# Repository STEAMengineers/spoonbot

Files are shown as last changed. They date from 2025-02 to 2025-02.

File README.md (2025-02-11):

# spoonbot
Spoonbot is a social energy indicator robot pcb based on a CH32v003J4M6 microcontroller, using a thumbwheel potentiometer to light some or all of the 5 leds.  It was designed for a smd soldering workshop we ran with MCQN at DoES Livepool.

This repo contains the code for the microcontroller and a kicad version of the pcb design. Because we used JLC colour silkscreen for our badges the hardware folder is an export from EasyEDA. It is highly recommended that you run DRC on the pcb before exporting for production.

Licence generated by OSHWA certification mark generator

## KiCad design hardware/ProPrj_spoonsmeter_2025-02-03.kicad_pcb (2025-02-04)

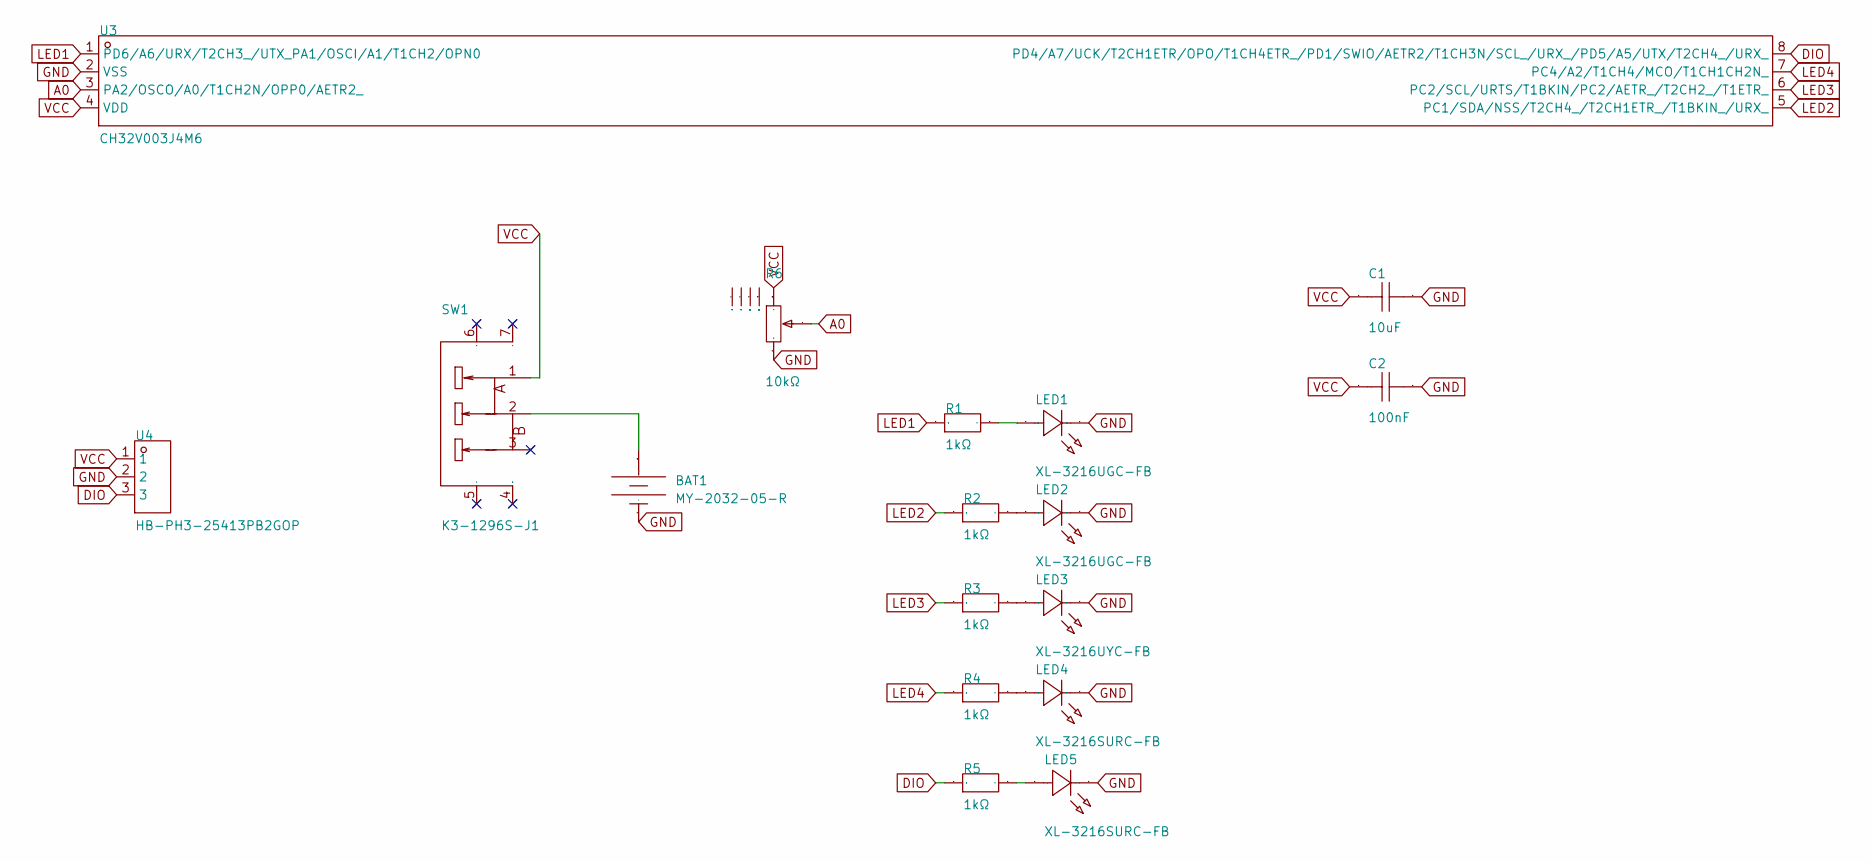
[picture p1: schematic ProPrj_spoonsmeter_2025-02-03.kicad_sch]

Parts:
BAT1: MY-2032-05-R; BAT-SMD_MY-2032-05-R; Manufacturer Part MY-2032-05-R; LCSC Part Name 电池扣 适用电池:CR2032
C1: 10uF; C0805; Manufacturer Part C0805X106K010T; LCSC Part Name 10uF ±10% 10V
C2: 100nF; C0805; Manufacturer Part C0805X104K251T; LCSC Part Name 100nF ±10% 250V
LED1, LED2: XL-3216UGC-FB; LED1206-RD_RED_LTST-C230CKT; Manufacturer Part XL-3216UGC-FB; LCSC Part Name XL-3216UGC-FB
LED3: XL-3216UYC-FB; LED1206-RD_RED_LTST-C230CKT; Manufacturer Part XL-3216UYC-FB; LCSC Part Name XL-3216UYC-FB
LED4, LED5: XL-3216SURC-FB; LED1206-RD_RED_LTST-C230CKT; Manufacturer Part XL-3216SURC-FB; LCSC Part Name XL-3216SURC-FB
R1, R2, R3, R4, R5: 1kΩ; R0805; Manufacturer Part SCR0805J1K; LCSC Part Name 厚膜电阻 1kΩ ±5% 125mW
R6: 10kΩ; RES-SMD_RK10J11R0A0H; Manufacturer Part RK10J11R0A0H; LCSC Part Name 10kΩ ±30%
SW1: K3-1296S-J1; SW-SMD_K3-1296S-J1; Manufacturer Part K3-1296S-J1; LCSC Part Name 柄长2.3mm卧贴双档 滑动开关
U3: CH32V003J4M6; SOP-8_L4.9-W3.8-P1.27-LS6.0-BL; Manufacturer Part CH32V003J4M6; LCSC Part Name CH32V003J4M6
U4: HB-PH3-25413PB2GOP; HDR-TH_3P-P2.54-V-M; Manufacturer Part HB-PH3-25413PB2GOP; LCSC Part Name 间距:2.54mm 1x3P 直插 方针

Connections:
$1N1644: BAT1.1 (+), SW1.2
$1N2487: LED3.2 (A), R3.2
$1N2528: LED2.2 (A), R2.2
$1N2533: LED4.2 (A), R4.2
$1N2535: LED1.2 (A), R1.2
$1N2553: LED5.2 (A), R5.2
A0: R6.2, U3.3 (PA2/OSCO/A0/T1CH2N/OPP0/AETR2_)
DIO: R5.1, U3.8 (PD4/A7/UCK/T2CH1ETR/OPO/T1CH4ETR_/PD1/S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), U4.3
GND: BAT1.2 (-), C1.2, C2.2, LED1.1 (K), LED2.1 (K), LED3.1 (K), LED4.1 (K), LED5.1 (K), R6.3, U3.2 (VSS), U4.2
LED1: R1.1, U3.1 (PD6/A6/URX/T2CH3_/UTX_PA1/OSCI/A1/T1CH2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)
LED2: R2.1, U3.5 (PC1/SDA/NSS/T2CH4_/T2CH1ETR_/T1BKIN_/UR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)
LED3: R3.1, U3.6 (PC2/SCL/URTS/T1BKIN/PC2/AETR_/T2CH2_/T1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)
LED4: R4.1, U3.7 (PC4/A2/T1CH4/MCO/T1CH1CH2N_)
VCC: C1.1, C2.1, R6.1, SW1.1, U3.4 (VDD), U4.1

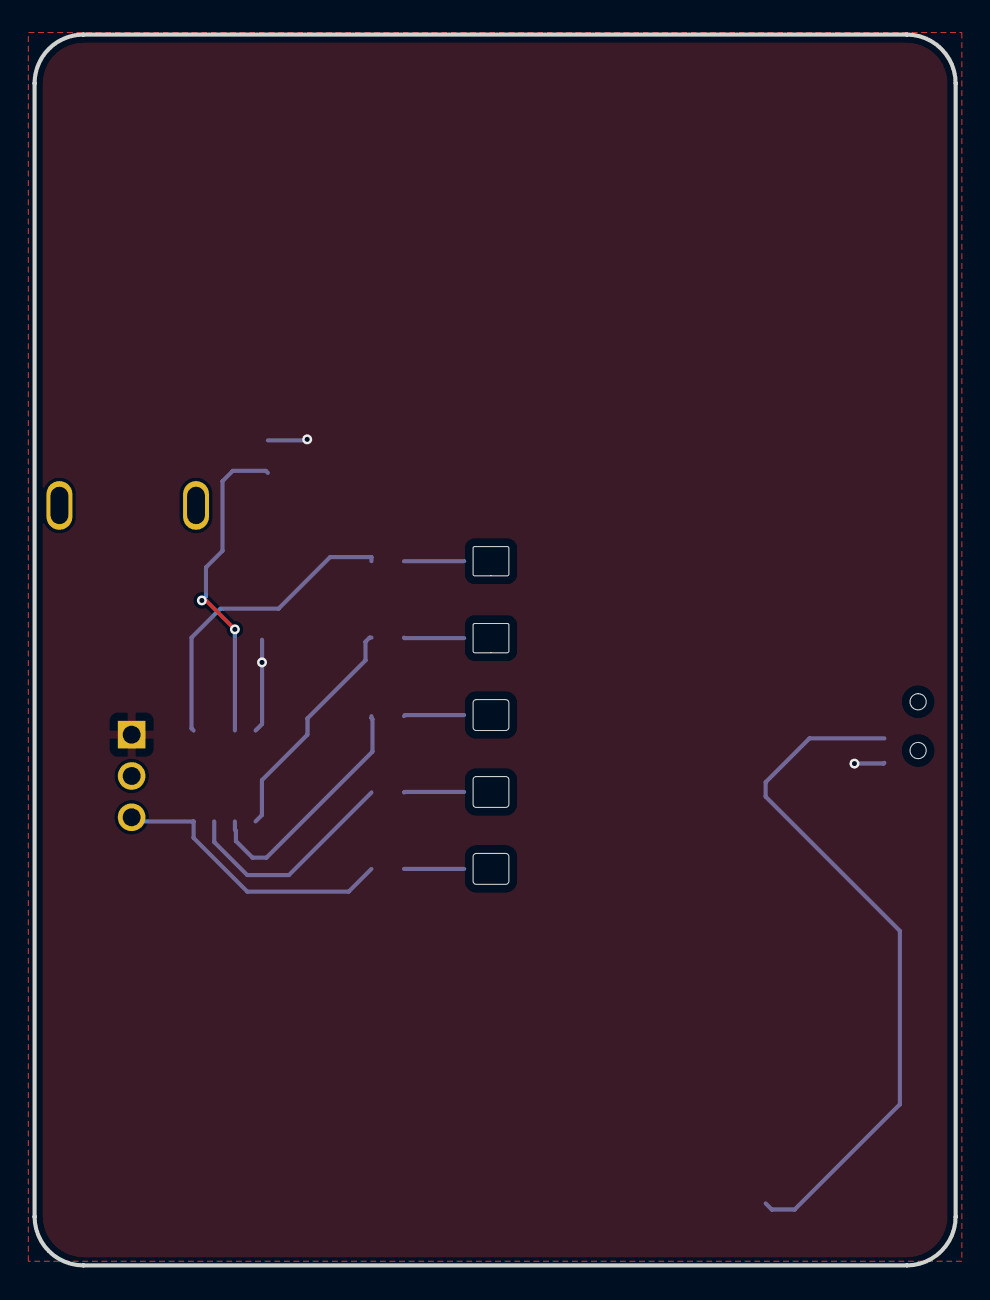
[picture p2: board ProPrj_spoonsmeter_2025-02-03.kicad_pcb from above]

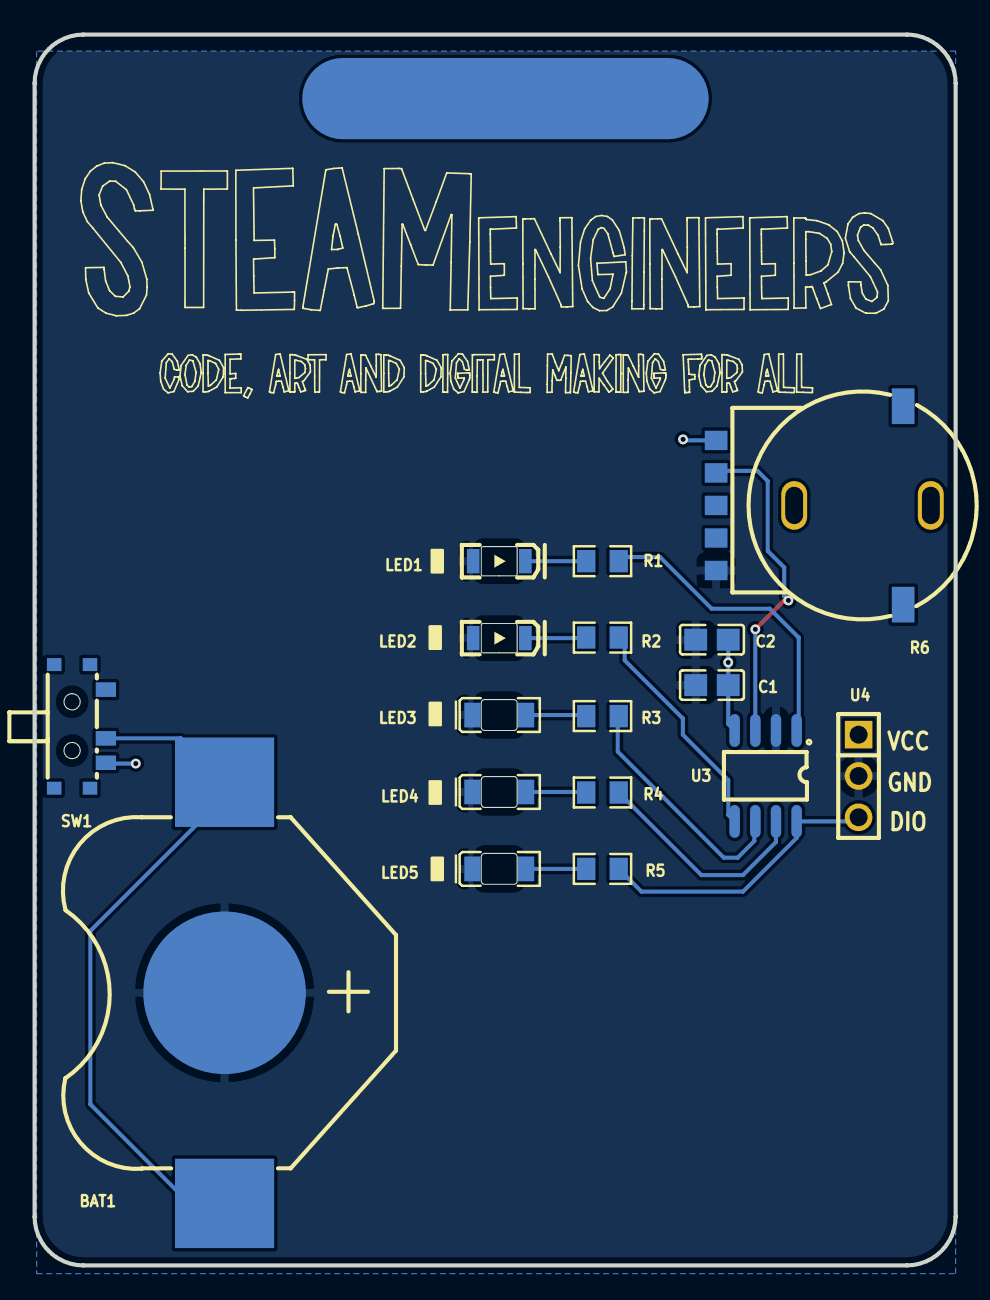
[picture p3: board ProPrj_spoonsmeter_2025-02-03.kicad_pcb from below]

Board: 2 copper layers, 56.6 x 75.7 mm, 17 parts (17 on the bottom side), 14 nets.

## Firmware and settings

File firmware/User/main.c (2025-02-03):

/********************************** (C) COPYRIGHT *******************************
 * File Name          : main.c
 * Author             : WCH
 * Version            : V1.0.0
 * Date               : 2023/12/25
 * Description        : Main program body.
 *********************************************************************************
 * Copyright (c) 2021 Nanjing Qinheng Microelectronics Co., Ltd.
 * Attention: This software (modified or not) and binary are used for 
 * microcontroller manufactured by Nanjing Qinheng Microelectronics.
 *******************************************************************************/

/*
 *@Note
 *Multiprocessor communication mode routine:
 *Master:USART1_Tx(PD5)\USART1_Rx(PD6).
 *This routine demonstrates that USART1 receives the data sent by CH341 and inverts
 *it and sends it (baud rate 115200).
 *
 *Hardware connection:PD5 -- Rx
 *                     PD6 -- Tx
 *
 */

#include "debug.h"


/* Global define */


/* Global Variable */
vu8 val;

/*********************************************************************
 * @fn      init_gpio
 *
 * @brief   Initializes PC1,2 & 4 and PA1.
 *
 * @return  none
 */
void init_gpio(void)
{
    ADC_InitTypeDef ADC_InitStructure = {0};
    GPIO_InitTypeDef  GPIO_InitStructure = {0};

    RCC_APB2PeriphClockCmd(RCC_APB2Periph_GPIOC | RCC_APB2Periph_GPIOA | RCC_APB2Periph_GPIOD, ENABLE);

    /* Port C1=led2 2=led3 4=led4 */
    GPIO_InitStructure.GPIO_Pin = GPIO_Pin_1 | GPIO_Pin_2 | GPIO_Pin_4;
    GPIO_InitStructure.GPIO_Speed = GPIO_Speed_30MHz;
    GPIO_InitStructure.GPIO_Mode = GPIO_Mode_Out_PP;
    GPIO_Init(GPIOC, &GPIO_InitStructure);

    /* Port D6=led1 D4=led5*/
    GPIO_InitStructure.GPIO_Pin = GPIO_Pin_6 | GPIO_Pin_4;
    GPIO_InitStructure.GPIO_Speed = GPIO_Speed_30MHz;
    GPIO_InitStructure.GPIO_Mode = GPIO_Mode_Out_PP;
    GPIO_Init(GPIOD, &GPIO_InitStructure);

    /* Port A0*/

     RCC_APB2PeriphClockCmd(RCC_APB2Periph_GPIOA, ENABLE);
     RCC_APB2PeriphClockCmd(RCC_APB2Periph_ADC1, ENABLE);
     RCC_ADCCLKConfig(RCC_PCLK2_Div8);

     GPIO_InitStructure.GPIO_Pin = GPIO_Pin_2;
     GPIO_InitStructure.GPIO_Mode = GPIO_Mode_AIN;
     GPIO_Init(GPIOA, &GPIO_InitStructure);
     
     ADC_DeInit(ADC1);
     ADC_InitStructure.ADC_Mode = ADC_Mode_Independent;
     ADC_InitStructure.ADC_ScanConvMode = DISABLE;
     ADC_InitStructure.ADC_ContinuousConvMode = ENABLE; 
     ADC_InitStructure.ADC_ExternalTrigConv = ADC_ExternalTrigConv_None; 
     ADC_InitStructure.ADC_DataAlign = ADC_DataAlign_Right;
     ADC_InitStructure.ADC_NbrOfChannel = 1; 
     ADC_Init(ADC1, &ADC_InitStructure);

     ADC_RegularChannelConfig(ADC1, ADC_Channel_0, 1, ADC_SampleTime_241Cycles);

     ADC_Cmd(ADC1, ENABLE);
     ADC_ResetCalibration(ADC1);
     while(ADC_GetResetCalibrationStatus(ADC1));
     ADC_StartCalibration(ADC1);
     while(ADC_GetCalibrationStatus(ADC1));

     ADC_SoftwareStartConvCmd(ADC1, ENABLE);


}

/*********************************************************************
 * @fn      blink
 *
 * @brief   toggle leds
 *
 * @return  none
 */
void blink_gpio(void)
{
    GPIO_WriteBit(GPIOC, GPIO_Pin_1, (GPIO_ReadOutputDataBit(GPIOC, GPIO_Pin_1) == Bit_SET) ? Bit_RESET : Bit_SET );
    Delay_Ms(50);

    GPIO_WriteBit(GPIOC, GPIO_Pin_2, (GPIO_ReadOutputDataBit(GPIOC, GPIO_Pin_2) == Bit_SET) ? Bit_RESET : Bit_SET );
    Delay_Ms(50);

    GPIO_WriteBit(GPIOC, GPIO_Pin_4, (GPIO_ReadOutputDataBit(GPIOC, GPIO_Pin_4) == Bit_SET) ? Bit_RESET : Bit_SET );
    Delay_Ms(50);

    GPIO_WriteBit(GPIOD, GPIO_Pin_6, (GPIO_ReadOutputDataBit(GPIOD, GPIO_Pin_6) == Bit_SET) ? Bit_RESET : Bit_SET );
    Delay_Ms(50);

    GPIO_WriteBit(GPIOD, GPIO_Pin_4, (GPIO_ReadOutputDataBit(GPIOD, GPIO_Pin_4) == Bit_SET) ? Bit_RESET : Bit_SET );
    Delay_Ms(50);

}
void Get_ADC_Val(void)
{
    uint16_t adcValue = ADC_GetConversionValue(ADC1);

    if(adcValue < 10)    
    {
        GPIO_WriteBit(GPIOD, GPIO_Pin_4, Bit_RESET ); //led5        
        GPIO_WriteBit(GPIOC, GPIO_Pin_4, Bit_RESET ); //led4
        GPIO_WriteBit(GPIOC, GPIO_Pin_2, Bit_RESET ); //led3
        GPIO_WriteBit(GPIOC, GPIO_Pin_1, Bit_RESET ); //led2
        GPIO_WriteBit(GPIOD, GPIO_Pin_6, Bit_RESET ); //led1       
    } else if(adcValue < 200) {
        GPIO_WriteBit(GPIOD, GPIO_Pin_4, Bit_SET ); //led5
        GPIO_WriteBit(GPIOC, GPIO_Pin_4, Bit_RESET ); //led4
        GPIO_WriteBit(GPIOC, GPIO_Pin_2, Bit_RESET ); //led3
        GPIO_WriteBit(GPIOC, GPIO_Pin_1, Bit_RESET ); //led2
        GPIO_WriteBit(GPIOD, GPIO_Pin_6, Bit_RESET ); //led1 
    } else if(adcValue < 400) {
        GPIO_WriteBit(GPIOD, GPIO_Pin_4, Bit_SET ); //led5
        GPIO_WriteBit(GPIOC, GPIO_Pin_4, Bit_SET ); //led4
        GPIO_WriteBit(GPIOC, GPIO_Pin_2, Bit_RESET ); //led3
        GPIO_WriteBit(GPIOC, GPIO_Pin_1, Bit_RESET ); //led2
        GPIO_WriteBit(GPIOD, GPIO_Pin_6, Bit_RESET ); //led1
    }  else if(adcValue < 600) {
        GPIO_WriteBit(GPIOD, GPIO_Pin_4, Bit_SET ); //led5
        GPIO_WriteBit(GPIOC, GPIO_Pin_4, Bit_SET ); //led4
        GPIO_WriteBit(GPIOC, GPIO_Pin_2, Bit_SET ); //led3
        GPIO_WriteBit(GPIOC, GPIO_Pin_1, Bit_RESET ); //led2
        GPIO_WriteBit(GPIOD, GPIO_Pin_6, Bit_RESET ); //led1 
    }  else if(adcValue < 800) {
        GPIO_WriteBit(GPIOD, GPIO_Pin_4, Bit_SET ); //led5
        GPIO_WriteBit(GPIOC, GPIO_Pin_4, Bit_SET ); //led4
        GPIO_WriteBit(GPIOC, GPIO_Pin_2, Bit_SET ); //led3
        GPIO_WriteBit(GPIOC, GPIO_Pin_1, Bit_SET ); //led2
        GPIO_WriteBit(GPIOD, GPIO_Pin_6, Bit_RESET ); //led1 
    } else {
        GPIO_WriteBit(GPIOD, GPIO_Pin_4, Bit_SET ); //led5
        GPIO_WriteBit(GPIOC, GPIO_Pin_4, Bit_SET ); //led4
        GPIO_WriteBit(GPIOC, GPIO_Pin_2, Bit_SET ); //led3
        GPIO_WriteBit(GPIOC, GPIO_Pin_1, Bit_SET ); //led2
        GPIO_WriteBit(GPIOD, GPIO_Pin_6, Bit_SET ); //led1  
    }
           
    // Delay_Ms(1000);
    
}


/*********************************************************************
 * @fn      main
 *
 * @brief   Main program.
 *
 * @return  none
 */
int main(void)
{
    NVIC_PriorityGroupConfig(NVIC_PriorityGroup_1);
    SystemCoreClockUpdate();
    Delay_Init();
  /*  USART_Printf_Init(115200);
    USARTx_CFG();
    printf("helllllo")
    Delay_Ms(3000); */
    init_gpio();
    blink_gpio();

    while(1) 
    {
    Get_ADC_Val();
    }
}

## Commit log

2025-02-03 Add kicad files
    [ProPrj_spoonsmeter_2025-02-03.kicad_pcb, ProPrj_spoonsmeter_2025-02-03.kicad_sch]
2025-02-04 Update kicad pcb files
    [ProPrj_spoonsmeter_2025-02-03.kicad_pcb]
